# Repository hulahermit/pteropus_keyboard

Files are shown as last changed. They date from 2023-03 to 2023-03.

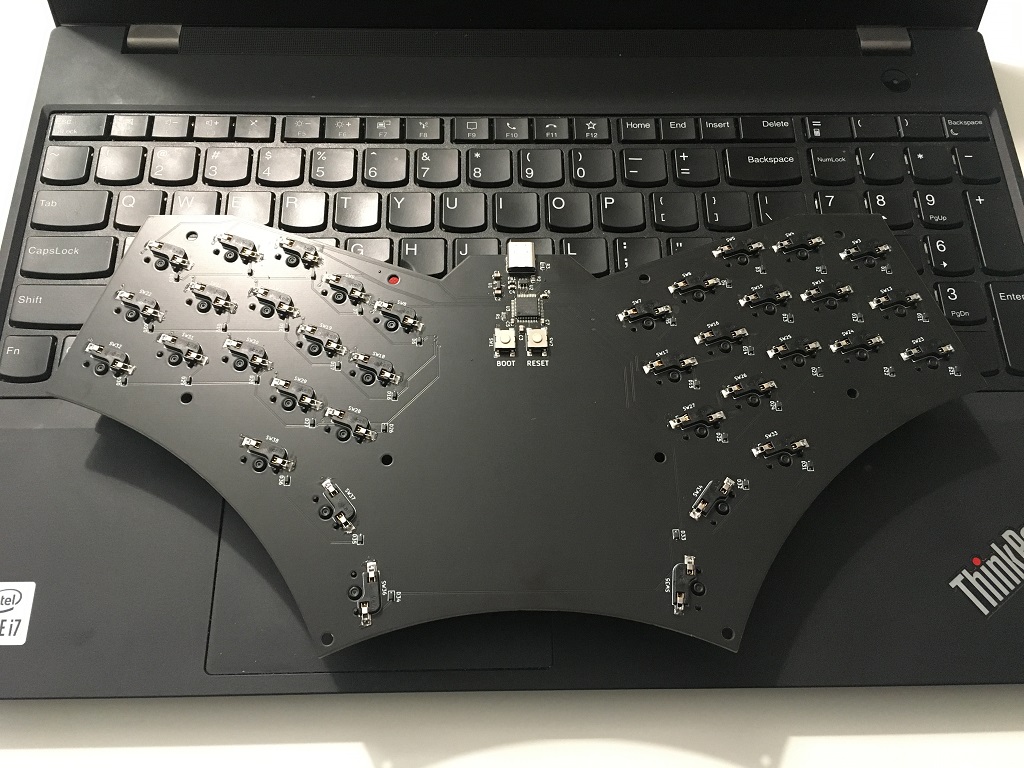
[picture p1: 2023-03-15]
images/IMG_4750.jpg

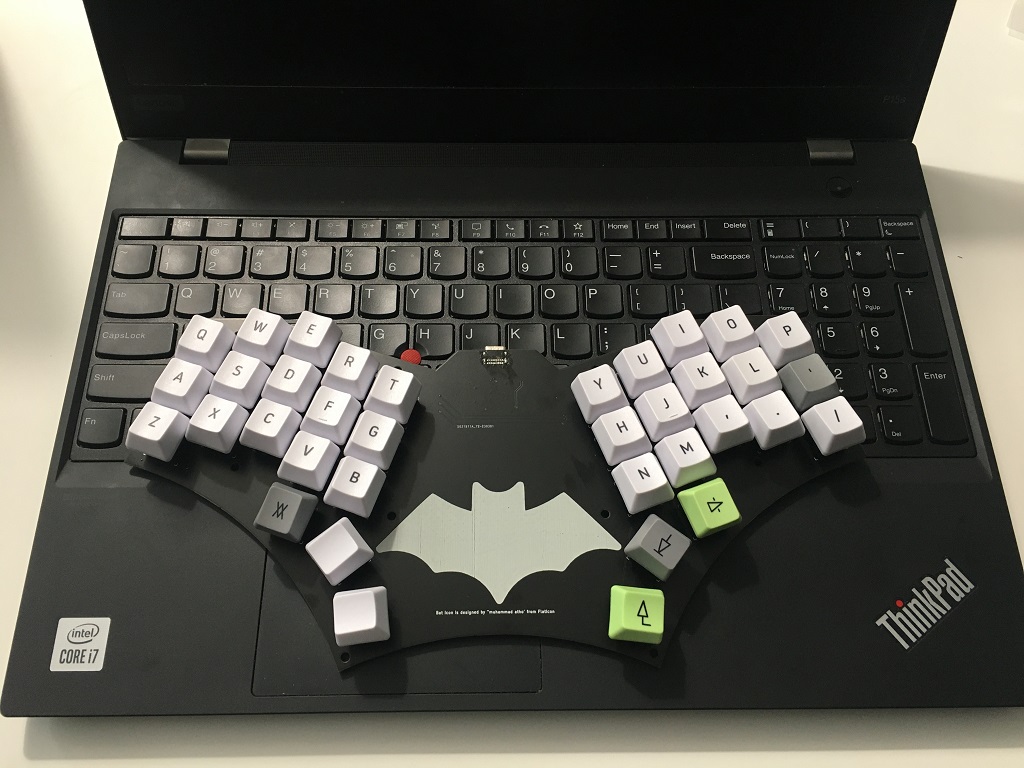
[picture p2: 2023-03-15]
images/IMG_4749.jpg

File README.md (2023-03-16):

pteropus keyboard
=================
pteropus
pteropus
Another Miryoku inspired 36-key keyboard.

After seeing the Miryoku layout on the web, I really wanted to try with a 36-key keyboard.

I looked some keyboards, like Iris, Crowboard, Kyria, etc., and I feel that I need to create keyboard geometry that fits my hands.

So I printed those layout and modify them to fit my hands and hopefully it will work.

Features
--------
This keyboard is a non-split linear staggered keyboard, like Crowboard or absolem.

Using a non-split keyboard, I can just use one microcontroller, and it simplify the design.

STM32F072 microcontroller
---------
This microcontroller is a crystal-less USB 2.0 controller, and it is embeded with serial resistors for USB_DP/USB_DM 

and a pull-up resistor for USB_DP, so it reduced the part count and simplify the trace routing.

Sourcing the keyboard
---------------------
This keyboard uses SMD components, except the type-c connector, so it came almost finished from the factory with PCB assembly service.

I use JLCPCB, so the part number shall be changed if use otherwise.

- BOM: pteropus BOM.csv
- Component position: pteropus-bottom-pos.csv

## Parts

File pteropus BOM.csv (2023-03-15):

Designator | Components | Footprint | LCSC Part Number | Qty
C1,C2,C3 | 1uF | Capacitor_SMD:C_0805_2012Metric | C28323 | 3
C4,C5,C6,C7 | 100nF | Capacitor_SMD:C_0603_1608Metric | C14663 | 4
D1,D2,D3,D4,D5,D6,D7,D8,D9,D10,D11,D12,D13,D14,D15,D16,D17,D18,D19,D20,D21,D22,D23,D24,D25,D26,D27,D28,D29,D30,D31,D32,D33,D34,D35,D36 | 1N5819WS | Diode_SMD:D_SOD-323 | C191023 | 36
FB1 | BLM18HE152SH1 | Resistor_SMD:R_0603_1608Metric | C596494 | 1
R1 | 10k | Resistor_SMD:R_0805_2012Metric | C17414 | 1
R2, R3 | 5.1k | Resistor_SMD:R_0805_2012Metric | C27834 | 2
SW1, SW2 | B3FS-1002P | Button_Switch_SMD:SW_SPST_Omron_B3FS-100xP | C87038 | 2
U1 | MCP1700x-330xxTT | Package_TO_SOT_SMD:SOT-23 | C39051 | 1
U2 | USBLC6-2SC6 | Package_TO_SOT_SMD:SOT-23-6 | C7519 | 1
U3 | STM32F072C8Tx | Package_QFP:LQFP-48_7x7mm_P0.5mm | C80488 | 1

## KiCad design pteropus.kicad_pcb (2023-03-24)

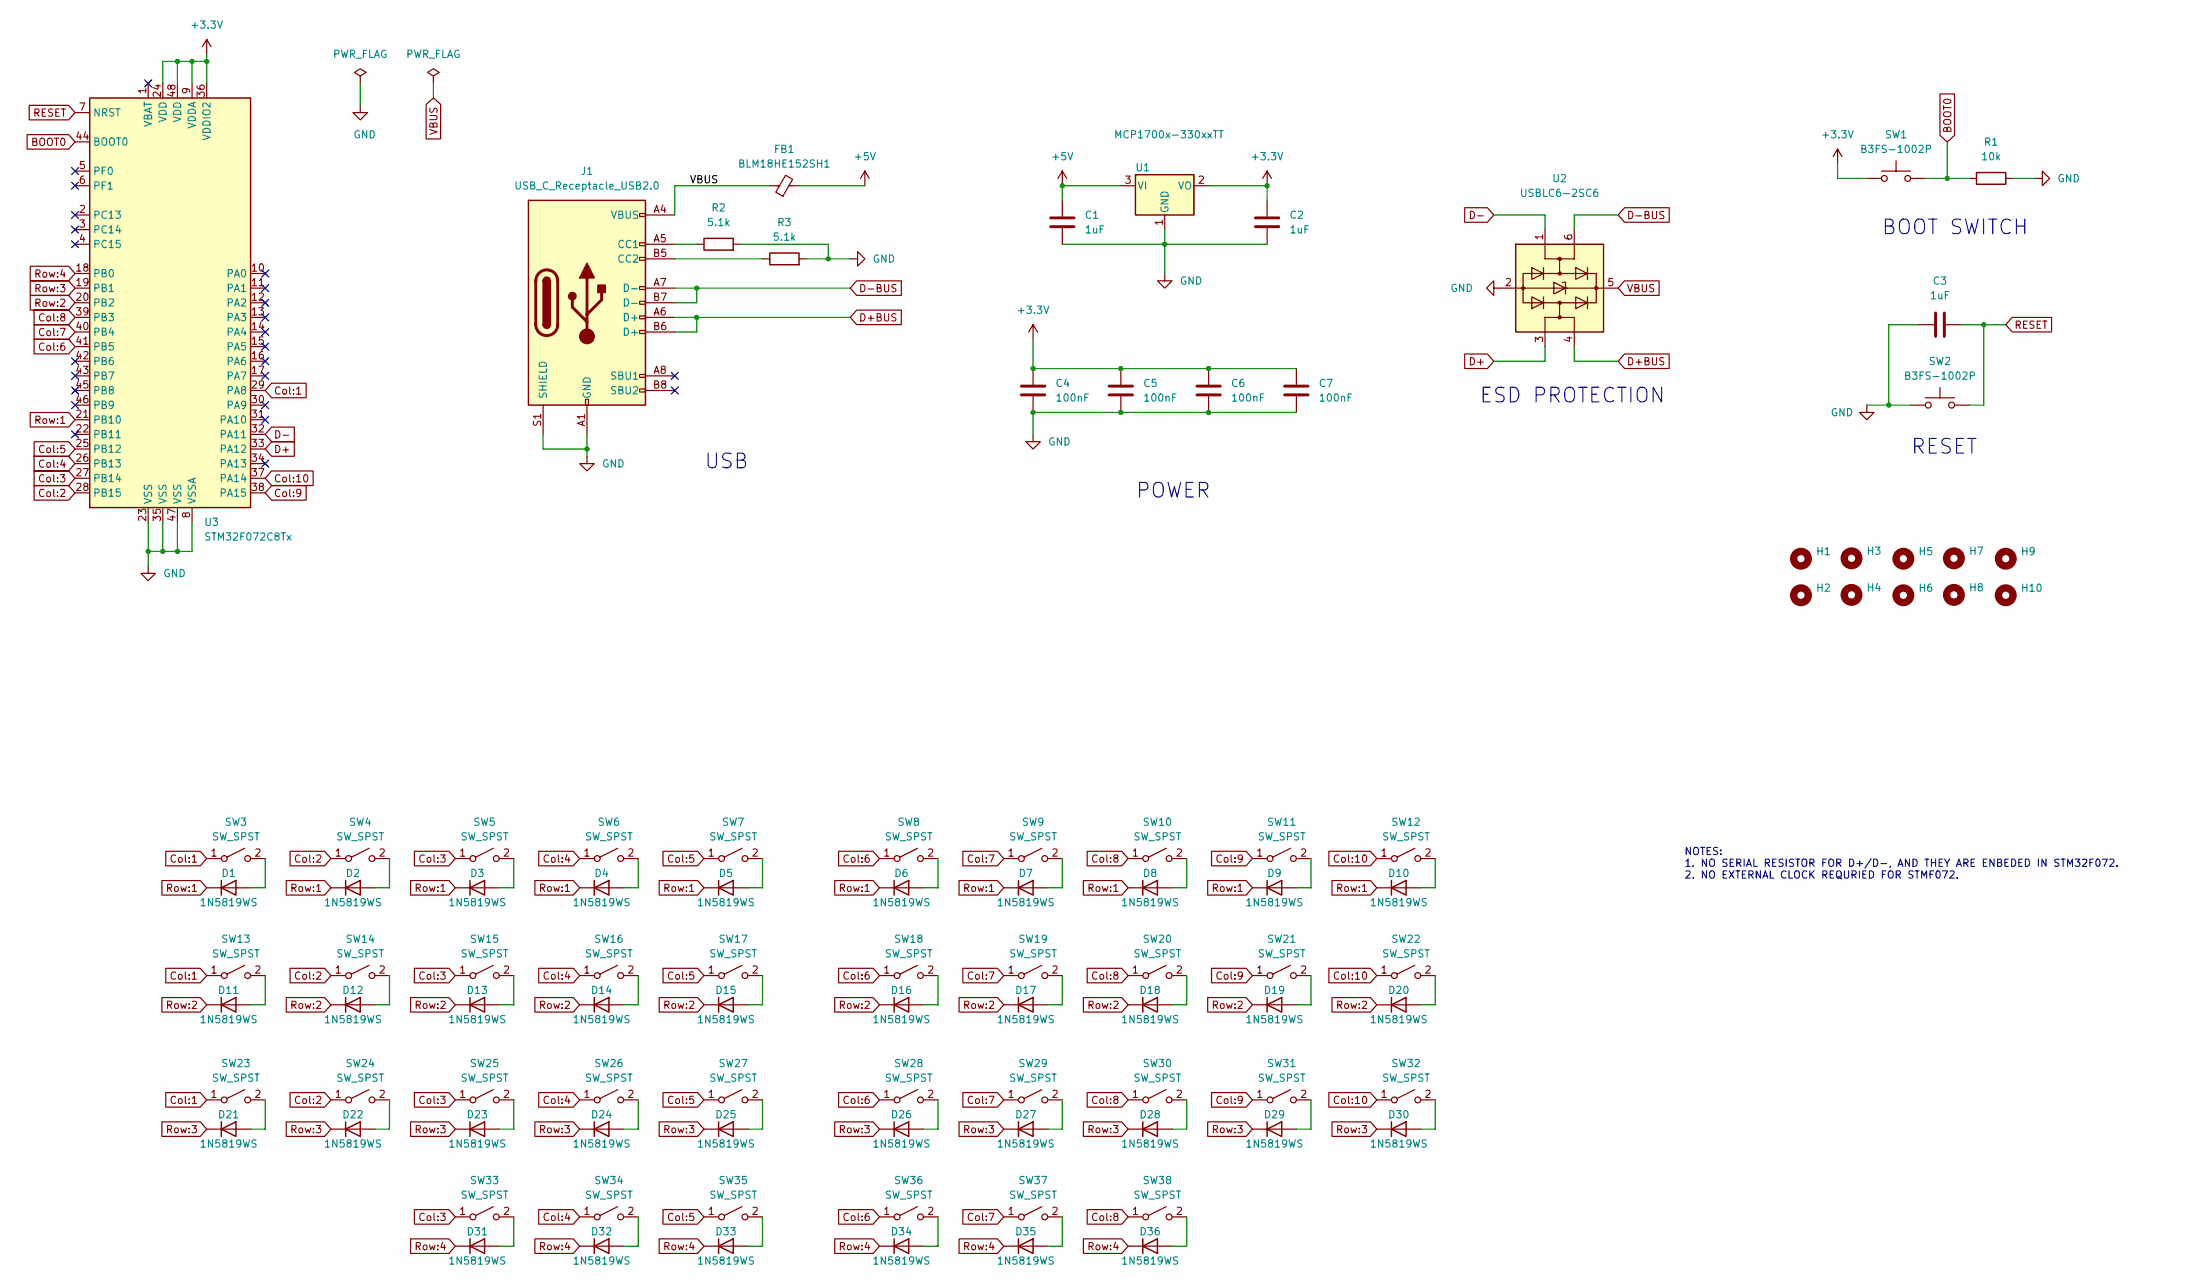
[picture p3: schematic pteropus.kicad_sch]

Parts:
C1, C2, C3: 1uF; C_0805_2012Metric; LCSC Part Number C28323
C4, C5, C6, C7: 100nF; C_0603_1608Metric; LCSC Part Number C14663
D1, D2, D3, D4, D5, D6, D7, D8, D9, D10, D11, D12, D13, D14, D15, D16, D17, D18, D19, D20, D21, D22, D23, D24, D25, D26, D27, D28, D29, D30, D31, D32, D33, D34, D35, D36: 1N5819WS; D_SOD-323; LCSC Part Number C191023
FB1: BLM18HE152SH1; R_0603_1608Metric; LCSC Part Number C596494
H1, H2, H3, H4, H5, H6, H7, H8, H9, H10: M3; MountingHole_3.2mm_M3_DIN965; LCSC Part Number n/a
J1: USB_C_Receptacle_USB2.0; USB_C_Receptacle_GCT_USB4085; LCSC Part Number n/a
R1: 10k; R_0805_2012Metric; LCSC Part Number C17414
R2, R3: 5.1k; R_0805_2012Metric; LCSC Part Number C27834
SW1, SW2: B3FS-1002P; SW_SPST_Omron_B3FS-100xP; LCSC Part Number C87038
SW3, SW4, SW5, SW6, SW7, SW8, SW9, SW10, SW11, SW12, SW13, SW14, SW15, SW16, SW17, SW18, SW19, SW20, SW21, SW22, SW23, SW24, SW25, SW26, SW27, SW28, SW29, SW30, SW31, SW32, SW33, SW34, SW35, SW36, SW37, SW38: SW_SPST; Kailh_socket_MX; LCSC Part Number n/a
U1: MCP1700x-330xxTT; SOT-23; LCSC Part Number C39051
U2: USBLC6-2SC6; SOT-23-6; LCSC Part Number C7519
U3: STM32F072C8Tx; LQFP-48_7x7mm_P0.5mm; LCSC Part Number C80488

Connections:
+3.3V: C2.1, C4.1, C5.1, C6.1, C7.1, SW1.1, U1.2 (VO), U3.9 (VDDA), U3.24 (VDD), U3.36 (VDDIO2), U3.48 (VDD)
+5V: C1.1, FB1.2, U1.3 (VI)
BOOT0: R1.2, SW1.2, U3.44 (BOOT0)
Col:1: SW3.1 (A), SW13.1 (A), SW23.1 (A), U3.29 (PA8)
Col:2: SW4.1 (A), SW14.1 (A), SW24.1 (A), U3.28 (PB15)
Col:3: SW5.1 (A), SW15.1 (A), SW25.1 (A), SW33.1 (A), U3.27 (PB14)
Col:4: SW6.1 (A), SW16.1 (A), SW26.1 (A), SW34.1 (A), U3.26 (PB13)
Col:5: SW7.1 (A), SW17.1 (A), SW27.1 (A), SW35.1 (A), U3.25 (PB12)
Col:6: SW8.1 (A), SW18.1 (A), SW28.1 (A), SW36.1 (A), U3.41 (PB5)
Col:7: SW9.1 (A), SW19.1 (A), SW29.1 (A), SW37.1 (A), U3.40 (PB4)
Col:8: SW10.1 (A), SW20.1 (A), SW30.1 (A), SW38.1 (A), U3.39 (PB3)
Col:9: SW11.1 (A), SW21.1 (A), SW31.1 (A), U3.38 (PA15)
Col:10: SW12.1 (A), SW22.1 (A), SW32.1 (A), U3.37 (PA14)
D+: U2.3 (I/O2), U3.33 (PA12)
D+BUS: J1.A6 (D+), J1.B6 (D+), U2.4 (I/O2)
D-: U2.1 (I/O1), U3.32 (PA11)
D-BUS: J1.A7 (D-), J1.B7 (D-), U2.6 (I/O1)
GND: C1.2, C2.2, C3.1, C4.2, C5.2, C6.2, C7.2, J1.A1 (GND), J1.A12 (GND), J1.B1 (GND), J1.B12 (GND), J1.S1 (SHIELD), R1.1, R2.2, R3.2, SW2.1, U1.1 (GND), U2.2 (GND), U3.8 (VSSA), U3.23 (VSS), U3.35 (VSS), U3.47 (VSS)
unnamed: D1.2 (A), SW3.2 (B)
unnamed: D2.2 (A), SW4.2 (B)
unnamed: D3.2 (A), SW5.2 (B)
unnamed: D4.2 (A), SW6.2 (B)
unnamed: D5.2 (A), SW7.2 (B)
unnamed: D6.2 (A), SW8.2 (B)
unnamed: D7.2 (A), SW9.2 (B)
unnamed: D8.2 (A), SW10.2 (B)
unnamed: D9.2 (A), SW11.2 (B)
unnamed: D10.2 (A), SW12.2 (B)
unnamed: D11.2 (A), SW13.2 (B)
unnamed: D12.2 (A), SW14.2 (B)
unnamed: D13.2 (A), SW15.2 (B)
unnamed: D14.2 (A), SW16.2 (B)
unnamed: D15.2 (A), SW17.2 (B)
unnamed: D16.2 (A), SW18.2 (B)
unnamed: D17.2 (A), SW19.2 (B)
unnamed: D18.2 (A), SW20.2 (B)
unnamed: D19.2 (A), SW21.2 (B)
unnamed: D20.2 (A), SW22.2 (B)
unnamed: D21.2 (A), SW23.2 (B)
unnamed: D22.2 (A), SW24.2 (B)
unnamed: D23.2 (A), SW25.2 (B)
unnamed: D24.2 (A), SW26.2 (B)
unnamed: D25.2 (A), SW27.2 (B)
unnamed: D26.2 (A), SW28.2 (B)
unnamed: D27.2 (A), SW29.2 (B)
unnamed: D28.2 (A), SW30.2 (B)
unnamed: D29.2 (A), SW31.2 (B)
unnamed: D30.2 (A), SW32.2 (B)
unnamed: D31.2 (A), SW33.2 (B)
unnamed: D32.2 (A), SW34.2 (B)
unnamed: D33.2 (A), SW35.2 (B)
unnamed: D34.2 (A), SW36.2 (B)
unnamed: D35.2 (A), SW37.2 (B)
unnamed: D36.2 (A), SW38.2 (B)
unnamed: J1.A5 (CC1), R2.1
unnamed: J1.B5 (CC2), R3.1
RESET: C3.2, SW2.2, U3.7 (NRST)
Row:1: D1.1 (K), D2.1 (K), D3.1 (K), D4.1 (K), D5.1 (K), D6.1 (K), D7.1 (K), D8.1 (K), D9.1 (K), D10.1 (K), U3.21 (PB10)
Row:2: D11.1 (K), D12.1 (K), D13.1 (K), D14.1 (K), D15.1 (K), D16.1 (K), D17.1 (K), D18.1 (K), D19.1 (K), D20.1 (K), U3.20 (PB2)
Row:3: D21.1 (K), D22.1 (K), D23.1 (K), D24.1 (K), D25.1 (K), D26.1 (K), D27.1 (K), D28.1 (K), D29.1 (K), D30.1 (K), U3.19 (PB1)
Row:4: D31.1 (K), D32.1 (K), D33.1 (K), D34.1 (K), D35.1 (K), D36.1 (K), U3.18 (PB0)
VBUS: FB1.1, J1.A4 (VBUS), J1.A9 (VBUS), J1.B4 (VBUS), J1.B9 (VBUS), U2.5 (VBUS)

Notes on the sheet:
POWER
ESD PROTECTION
BOOT SWITCH
USB
NOTES: 1. NO SERIAL RESISTOR FOR D+/D-, AND THEY ARE ENBEDED IN STM32F072. 2. NO EXTERNAL CLOCK REQURIED FOR STMF072.
RESET

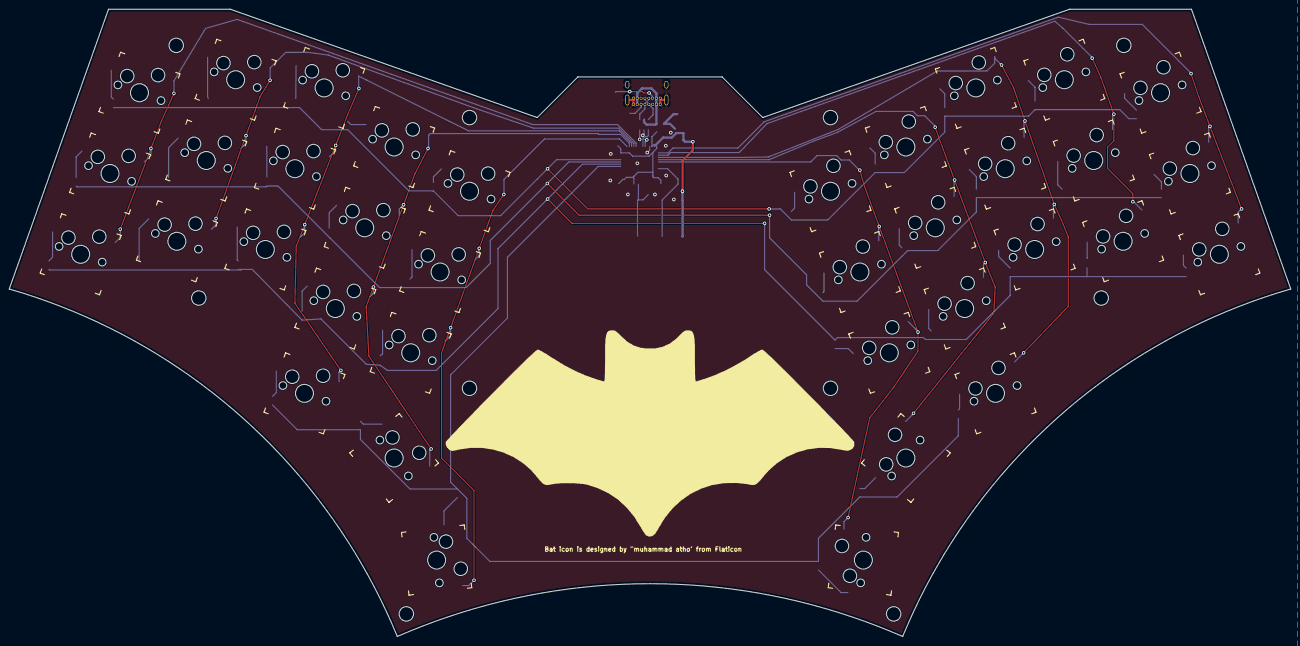
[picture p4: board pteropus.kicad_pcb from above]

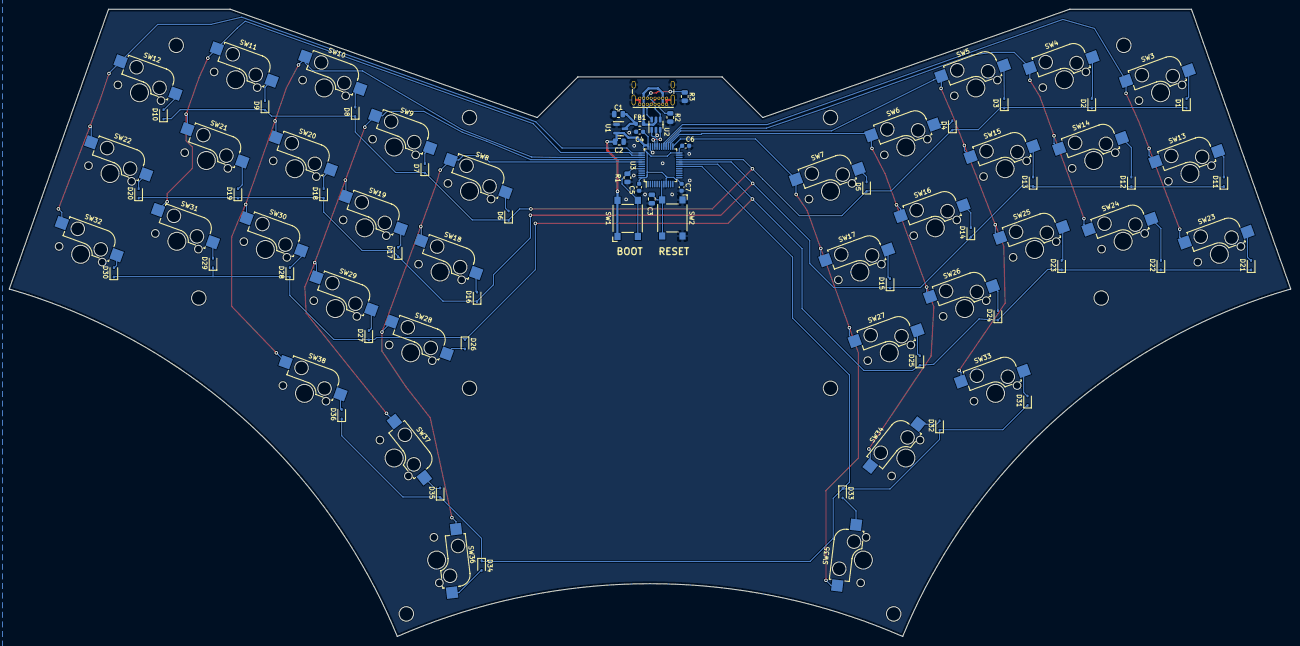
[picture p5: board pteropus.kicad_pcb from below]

Board: 2 copper layers, 284.0 x 139.0 mm, 99 parts (53 on the bottom side), 62 nets.

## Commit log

2023-03-15 Add images and update BOM
2023-03-15 Update BOM.
    [pteropus BOM.csv]
2023-03-24 Relocate D29 diode.
    [pteropus-B_Cu.gbr, pteropus-B_Mask.gbr, pteropus-B_Paste.gbr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]
